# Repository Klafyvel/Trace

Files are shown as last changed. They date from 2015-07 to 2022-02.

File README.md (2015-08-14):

Trace
=====

Trace est un projet ayant pour but de créer une traçeuse à commande numérique. Le projet comprend :
- Un utilitaire python pour formater le GCode et le stramer via une liason série à la machine
- Le code (arduino) de la machine qui interprète le GCode et contrôle la machine
- Le plan de la machine (électronique + mécanique)

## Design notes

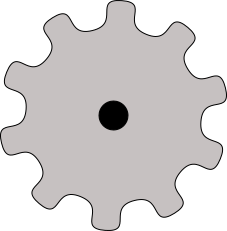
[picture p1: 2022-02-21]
PCInterface/work.png

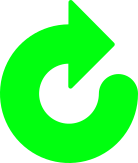
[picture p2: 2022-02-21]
PCInterface/reload.png

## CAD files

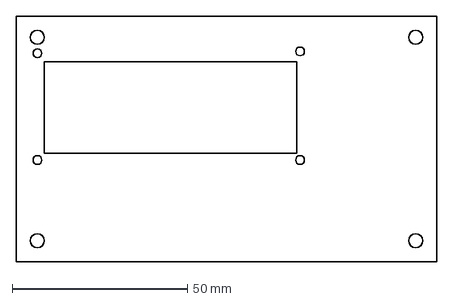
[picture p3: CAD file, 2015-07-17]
Plan/PanneauSuperieur.dxf
120.0 x 70.0 mm

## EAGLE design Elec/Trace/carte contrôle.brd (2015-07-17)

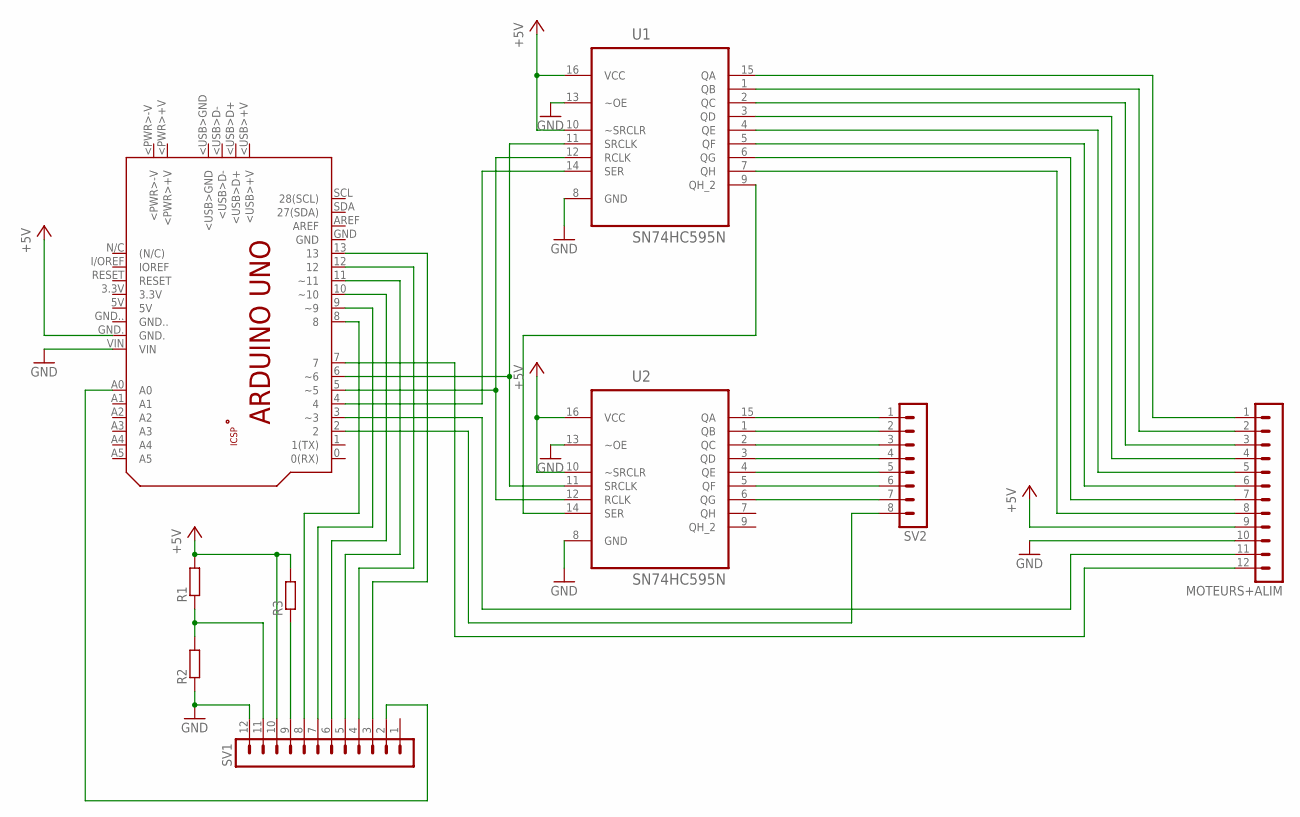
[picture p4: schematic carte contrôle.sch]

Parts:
MOTEURS+ALIM: MA12-1
PCB1: ARDUINO_UNO
R1, R2, R3: R-EU_0207/10; 0207/10
SV1: MA12-1
SV2: MA08-1
U1, U2: SN74HC595N; DIP254P762X508-16

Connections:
+5V: MOTEURS+ALIM.9, PCB1.GND., R1.2, R3.2, SV1.10, U1.10 (~SRCLR), U1.16 (VCC), U2.10 (~SRCLR), U2.16 (VCC)
GND: MOTEURS+ALIM.10, PCB1.VIN, R2.1, SV1.12, U1.8 (GND), U1.13 (~OE), U2.8 (GND), U2.13 (~OE)
unnamed: U1.9 (QH_2), U2.14 (SER)
unnamed: MOTEURS+ALIM.1, U1.15 (QA)
unnamed: MOTEURS+ALIM.2, U1.1 (QB)
unnamed: MOTEURS+ALIM.3, U1.2 (QC)
unnamed: MOTEURS+ALIM.4, U1.3 (QD)
unnamed: MOTEURS+ALIM.5, U1.4 (QE)
unnamed: MOTEURS+ALIM.6, U1.5 (QF)
unnamed: MOTEURS+ALIM.7, U1.6 (QG)
unnamed: MOTEURS+ALIM.8, U1.7 (QH)
unnamed: PCB1.5 (~5), U1.12 (RCLK), U2.12 (RCLK)
unnamed: PCB1.6 (~6), U1.11 (SRCLK), U2.11 (SRCLK)
unnamed: PCB1.4, U1.14 (SER)
unnamed: SV2.1, U2.15 (QA)
unnamed: SV2.2, U2.1 (QB)
unnamed: SV2.3, U2.2 (QC)
unnamed: SV2.4, U2.3 (QD)
unnamed: SV2.5, U2.4 (QE)
unnamed: SV2.6, U2.5 (QF)
unnamed: SV2.7, U2.6 (QG)
unnamed: MOTEURS+ALIM.11, PCB1.3 (~3)
unnamed: PCB1.2, SV2.8
unnamed: PCB1.8, SV1.8
unnamed: R1.1, R2.2, SV1.11
unnamed: PCB1.9 (~9), SV1.7
unnamed: PCB1.10 (~10), SV1.6
unnamed: PCB1.11 (~11), SV1.5
unnamed: PCB1.12, SV1.4
unnamed: PCB1.13, SV1.3
unnamed: R3.1, SV1.9
unnamed: PCB1.A0, SV1.2
unnamed: MOTEURS+ALIM.12, PCB1.7

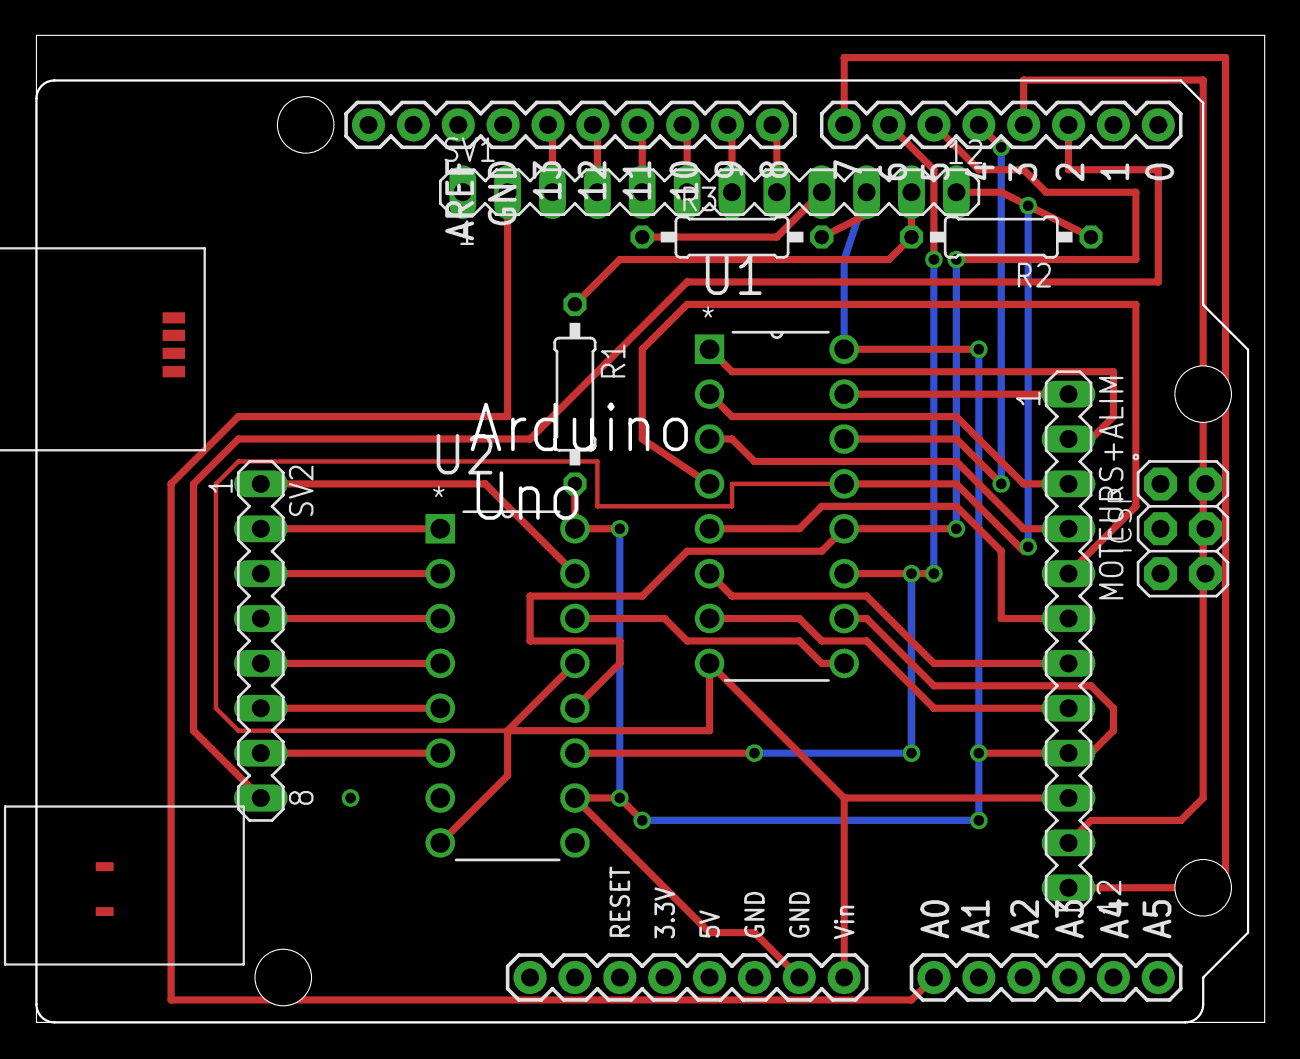
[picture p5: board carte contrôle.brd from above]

Board: 2 copper layers, 69.5 x 55.9 mm, 9 parts (0 on the bottom side), 33 nets.

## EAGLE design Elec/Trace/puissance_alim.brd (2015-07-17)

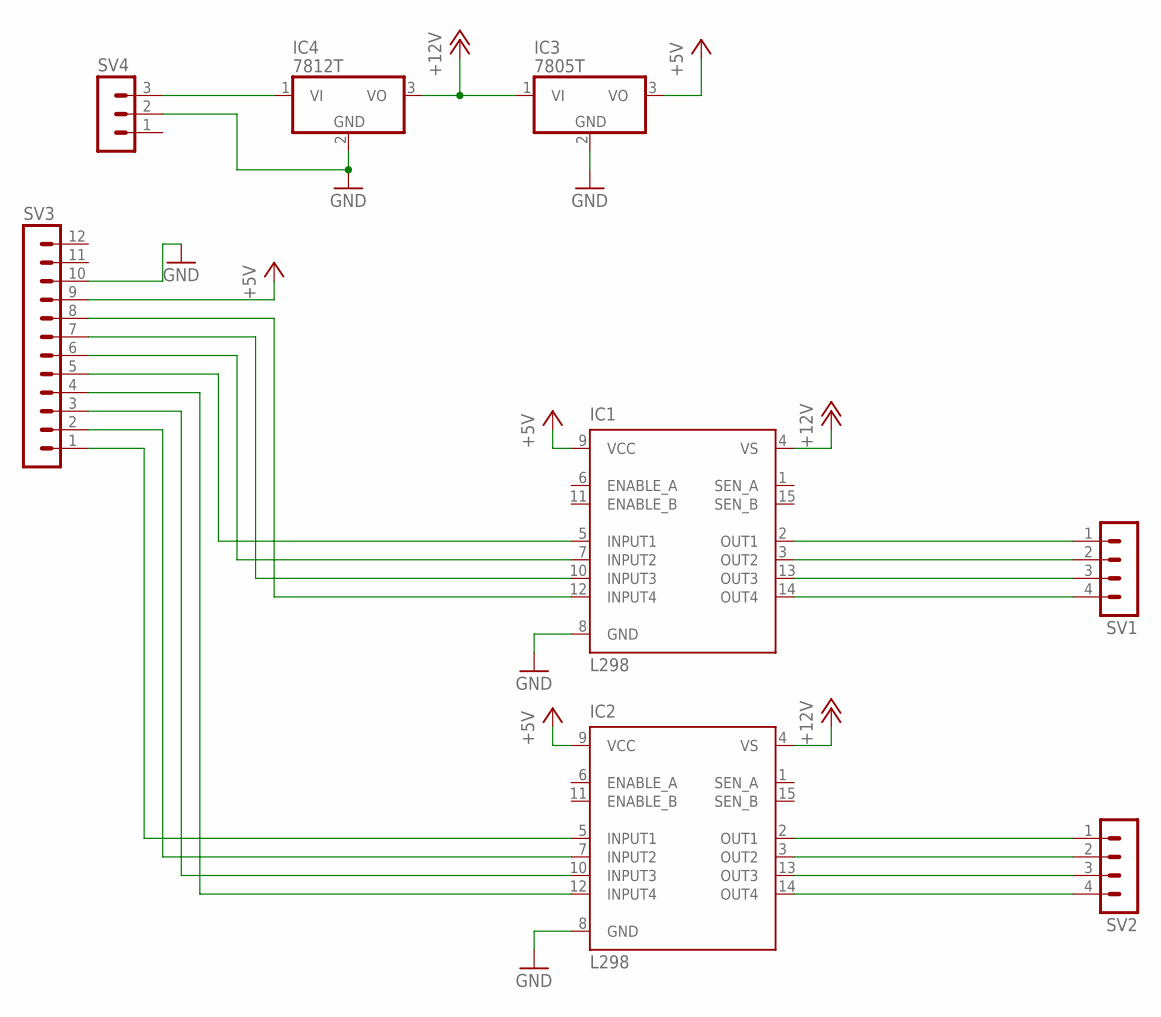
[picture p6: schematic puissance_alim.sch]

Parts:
IC1, IC2: L298; MULTIWATT-15
IC3: 7805T; TO220H
IC4: 7812T; TO220H
SV1, SV2: MA04-1
SV3: MA12-1
SV4: MA03-1

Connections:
+5V: IC1.9 (VCC), IC2.9 (VCC), IC3.3 (VO), SV3.9
+12V: IC1.4 (VS), IC2.4 (VS), IC3.1 (VI), IC4.3 (VO)
GND: IC1.8 (GND), IC2.8 (GND), IC3.2 (GND), IC4.2 (GND), SV3.10, SV4.2
unnamed: IC2.5 (INPUT1), SV3.1
unnamed: IC2.7 (INPUT2), SV3.2
unnamed: IC2.10 (INPUT3), SV3.3
unnamed: IC2.12 (INPUT4), SV3.4
unnamed: IC1.5 (INPUT1), SV3.5
unnamed: IC1.7 (INPUT2), SV3.6
unnamed: IC1.10 (INPUT3), SV3.7
unnamed: IC1.12 (INPUT4), SV3.8
unnamed: IC1.2 (OUT1), SV1.1
unnamed: IC1.3 (OUT2), SV1.2
unnamed: IC1.13 (OUT3), SV1.3
unnamed: IC1.14 (OUT4), SV1.4
unnamed: IC2.2 (OUT1), SV2.1
unnamed: IC2.3 (OUT2), SV2.2
unnamed: IC2.13 (OUT3), SV2.3
unnamed: IC2.14 (OUT4), SV2.4
unnamed: IC4.1 (VI), SV4.3

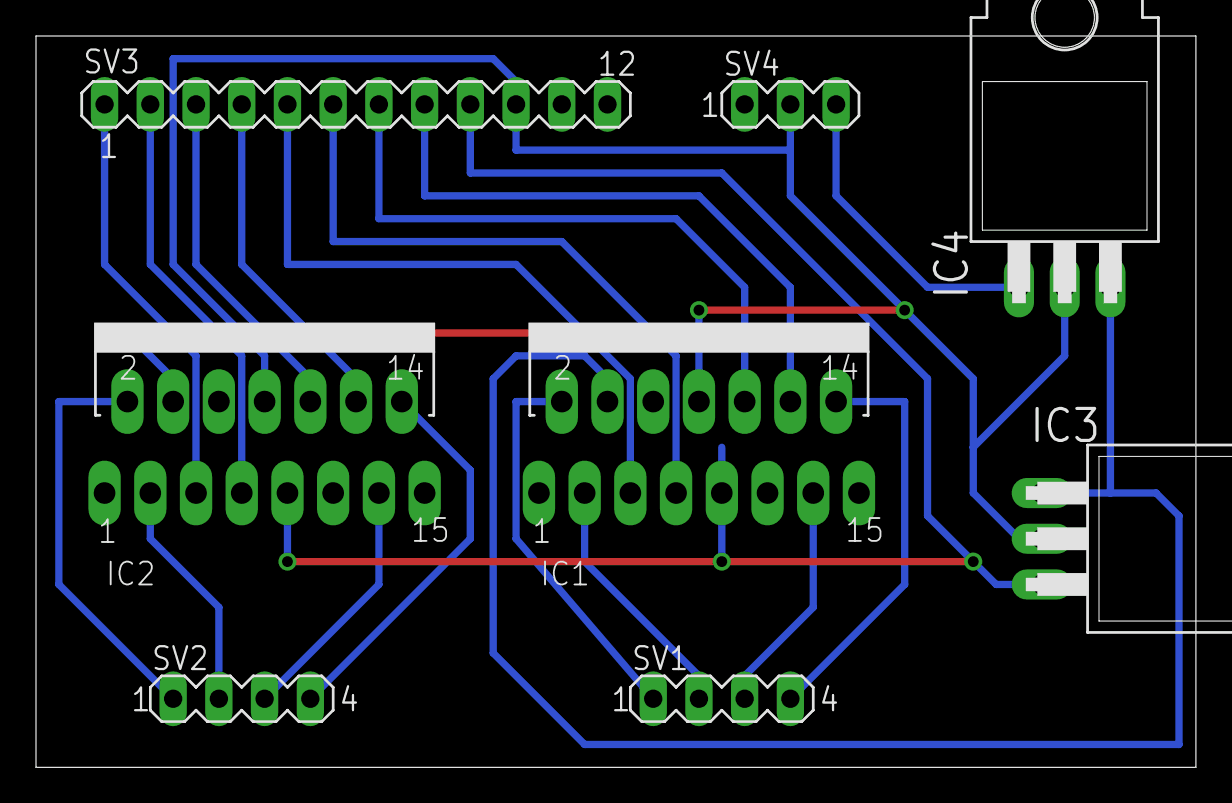
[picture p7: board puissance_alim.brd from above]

Board: 2 copper layers, 64.4 x 40.6 mm, 8 parts (0 on the bottom side), 20 nets.

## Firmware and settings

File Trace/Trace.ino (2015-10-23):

#include "LiquidCrystal.h"
#include "Servo.h"

#include "menu.h"
#include "settings.h"
#include "communication.h"
#include "gcode.h"
#include "machine.h"
#include "ShiftRegister/shiftRegister.h"
#include "shiftRegisteredInput.h"

#include "ShiftRegister/shiftRegister.cpp"

LiquidCrystal lcd(13,12,11,10,9,8);

#define BP_UP 1
#define BP_DOWN 0
#define BP_OK 2

#define SHCP 6
#define STCP 5
#define DS 4

#define SERVO_PIN 9

Servo servo;

ShiftRegister sr(SHCP,STCP,DS);

ShiftRegisteredInput sri(&sr, 8, 16, 2);

Menu myMenu("Menu principal", &lcd, &sri, BP_UP, BP_DOWN, BP_OK);

Machine machine = Machine();

uint8_t servoHaut = 90;
uint8_t servoBas = 90;

void setup()
{
    Serial.begin(9600);
    lcd.begin(16, 2);
    lcd.print("Bienvenue");
    uint8_t test[] = {0xFF, 0xFF};
    sr.sendBytes(test, 2);
    test[0] = 0;
    test[1] = 0;
    delay(15000);
    //sr.sendBytes(test, 2);

    servo.attach(SERVO_PIN);
    servo.write(servoHaut);

    myMenu.addItem(&reglageServo, "Reglage du servo");
    myMenu.addItem(&testServo, "Test du servo");
    myMenu.addItem(&testGCode, "Test gcode");
    myMenu.addItem(&testUnipolar, "Test unipolaire");

    machine.addStepperAxis(X, 20, 1);
    machine.addStepperAxis(Y, 20, 1);
    machine.addServoAxis(Z, 2, 80, 100);

}
void loop()
{
    int action = myMenu.choose();
    if(action != -1)
    {
        myMenu.action(action);
    }

}
void reglageServo()
{
    Menu menuReglage("Reglage du servo", &lcd, BP_UP, BP_DOWN, BP_OK);
    menuReglage.addItem(&reglageServoHaut, "Position haute");
    menuReglage.addItem(&reglageServoBas, "Position basse");
    int action = menuReglage.choose();
    if(action != -1)
    {
        menuReglage.action(action);
    }

}
void reglageServoHaut()
{
    lcd.clear();
    lcd.print("Regl. servo haut");
    lcd.setCursor(0,1);
    lcd.print("Enregistrer : OK");
    uint8_t val = servoHaut;
    while(digitalRead(BP_OK)){
        val = (float)(analogRead(0))/1023.0*180.0;
        servo.write(val);
        dvar(val);
    }
    servoHaut = val;
    servo.write(servoHaut);
}

void reglageServoBas()
{
    lcd.clear();
    lcd.print("Regl. servo bas");
    lcd.setCursor(0,1);
    lcd.print("Enregistrer : OK");
    uint8_t val = servoBas;
    while(digitalRead(BP_OK)){
        val = (float)(analogRead(0))/1023.0*180.0;
        servo.write(val);
    }
    servoBas = val;
    servo.write(servoHaut);
}

void testServo()
{
    lcd.clear();
    lcd.print("Test du servo");
    for(int i=0; i<10000; i++){
        servo.write(servoHaut);
        delay(10);
        servo.write(servoBas);
        delay(10);
    }
    servo.write(servoHaut);
}

void testGCode()
{
    lcd.clear();
    lcd.print("Test du gcode...");
    Command cmd = parse("G01 Z-1.000000 F100.0(Penetrate)");
    dvar(cmd.num);
    for(int i=0; i<NB_ARGS; i++){
        dvar(cmd.args[i]);
    }

}
void testUnipolar()
{
    lcd.clear();
    lcd.print("Test axe unipolaire");
    StepperAxis axe = StepperAxis(20, 5);
    // axe.move(42);
    while(!axe.currentMoveFinished())
    {
        uint8_t o = axe.getOutput() << 4;
        axe.move();
        uint8_t toSend[] = {o,0}; // sweet smiley
        sr.sendBytes(toSend, 2); 
    }
}

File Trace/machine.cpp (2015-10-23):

#include "machine.h"

#define SQUARE(A) A*A

Machine::Machine()
{
    for (int i = 0; i < NB_AXIS; ++i)
    {
        this->axes[i] = 0;
        this->pos[i] = 0;
        this->currentSteps[i] = 0;
    }
}
Machine::~Machine()
{
    for (int i = 0; i < NB_AXIS; ++i)
        delete this->axes[i];
}

void Machine::addStepperAxis(uint8_t code, long stepTime, int stepSize)
{
    if (this->axes[code] != 0)
        delete this->axes[code];
    this->axes[code] = new StepperAxis(stepTime, stepSize);
}

void Machine::addServoAxis(uint8_t code, uint8_t pin, uint8_t up, uint8_t down)
{
    if (this->axes[code] != 0)
        delete this->axes[code];
    this->axes[code] = new ServoAxis(pin, up, down);
}

void Machine::execute(Command command)
{
    bool move = false;
    switch (command.num)
    {
        case G00:case G01: this->linearInterpolation(command.args);move=true;break;
        default: break;
    }
    if (move)
    {
        for (int i = 0; i < NB_AXIS; ++i)
        {
            for (int j = 0; j < this->currentSteps[i]; ++j)
            {
                this->axes[j]->move();
                delay(this->axes[j]->getStepTime());
            }
        }
    }
}

void Machine::linearInterpolation(float args[]) 
{
    for (int i = 0; i < NB_AXIS; ++i)
    {
        this->currentSteps[i] = abs(args[i] - this->pos[i]) / this->axes[i]->getStepSize();
        this->axes[i]->addMovement(args[i]);
        this->pos[i] = args[i];
    }
}

void Machine::cicularInterpolationClockwise(float args[])
{
    float radius = sqrt(args[I]*args[I] + args[J]*args[J] + args[K]*args[K]);
    for (int i = 0; i < NB_AXIS; ++i)
    {
        this->currentSteps[i] = acos(this->axes[i]->getStepSize()/radius);
    }
}
void Machine::cicularInterpolationCounterClockwise(float args[])
{
    float radius = sqrt(args[I]*args[I] + args[J]*args[J]);
    float arc = 2 * PI * radius;
    float stepArc = sqrt(SQUARE(this->axes[X]->getStepSize()) + SQUARE(this->axes[Y]->getStepSize()));
    for (int i = 0; i < (arc / stepArc); ++i)
    {
        this->axes[X]->addMovement(cos(i)*radius);
        this->axes[Y]->addMovement(-sin(i)*radius);
    }

}

ServoAxis::ServoAxis(uint8_t pin, uint8_t up, uint8_t down)
{
    this->up = up;
    this->down = down;
    this->servo.attach(pin);
}

void ServoAxis::move()
{
    if (this->waitingMovement.getLength() <= 0)
        return;
    float value = this->waitingMovement.popFirst();
    if (value >= 0)
        this->servo.write(this->up);
    else
        this->servo.write(this->down);
}

StepperAxis::StepperAxis(long stepTime, int stepSize)
{
    this->lastTime = millis();
    this->stepTime = stepTime;
    this->stepSize = stepSize;
    this->remainingDistance = 0;
    this->lastPos = 1;
}
void StepperAxis::move()
{
    if(this->remainingDistance <= 0 && this->waitingMovement.getLength() > 0) 
    {
        this->remainingDistance = this->waitingMovement.popFirst();
        this->lastTime = millis();
        this->movementDirection = this->remainingDistance / abs(this->remainingDistance);
    }
    else if(millis() - this->lastTime >= this->stepTime){
        this->remainingDistance += this->stepSize * this->movementDirection;
        this->lastPos = (this->lastPos * 2) % 16 + (this->lastPos == 8);
        this->lastTime = millis();
    }
}
uint8_t StepperAxis::getOutput() const
{
    return this->lastPos;
}
bool StepperAxis::currentMoveFinished() const
{
    return (this->remainingDistance <= 0);
}

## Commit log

2015-05-10 Ajout des fichiers
2015-07-01 POO + output for steppers
2015-07-03 Modification de l'interface
2015-07-04 Modification mineure de l'interface
2015-07-04 Liste des ports série disponibles.
2015-07-04 Ajout d'une option pour les logs.
2015-07-16 Commentaire explicatif pour les unités
2015-07-16 Moteurs bipolaires et unipolaires gérés par la même classe.
2015-07-17 Ajout de la lib pour le contrôle des 74HC595
2015-07-17 Ajout du début du plan de la machine.
    [PanneauSuperieur.dxf]
2015-07-17 Ajout des schémas électriques.
    [Trace.sch, carte contrôle.brd, carte contrôle.sch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]
2015-08-06 Valeurs définie en cas de non spécification d'argument dans une commande.
2015-08-06 Ajout du nom du site dans le schéma.
    [Trace.sch]
2015-08-06 Rapport de performance du module ShiftRegister par vinvin-win
2015-08-07 fichier log + correction bug mineur sur le mode manuel + adaptation de l'envoi de fichier.
    [window.py]
2015-08-07 Interface des contrôles manuels.
2015-08-07 Icônes pour l'interface et action sur la pluspart des commandes.
2015-08-08 meilleure gestion des commentaires
2015-08-08 Fichier svg des icônes.
2015-08-08 Ajout de la license.
2015-08-08 Fichiers de l'application.
2015-08-17 Envoi de fichier fonctionnel
2015-08-17 Correction d'un bug du bouton X- et gestion de l'imprécision du calcul sur les petits arcs
    [window.py]
2015-08-17 Gestion des variables dans le G-code
2015-10-22 Fonction de dessin plus courte.
2015-10-22 Ajout de l'option 'effectuer les calculs'.
2015-10-22 Inversion de l'axe y dans la vue de fichier.
2015-10-23 Remise à 0 du texte de la fenêtre du préprocesseur.
2015-10-23 Suppression de la segfault à la fermeture du programme.
2015-10-23 Ajout de la lib Listuino.
2015-10-23 Beaucoup de code non commité...
2015-10-28 Ajout d'une simulation basique de port série et d'un fichier gcode exemple.
2022-02-21 [ImgBot] Optimize images
    *Total -- 57.97kb -> 41.99kb (27.56%)
    /PCInterface/traceIcon.svg -- 2.74kb -> 1.05kb (61.66%)
    /PCInterface/icons.svg -- 23.45kb -> 15.20kb (35.16%)
    /PCInterface/reload.png -- 3.98kb -> 2.95kb (25.81%)
    /PCInterface/save.png -- 1.56kb -> 1.18kb (24.15%)
    /PCInterface/work.png -- 12.37kb -> 9.42kb (23.87%)
    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
